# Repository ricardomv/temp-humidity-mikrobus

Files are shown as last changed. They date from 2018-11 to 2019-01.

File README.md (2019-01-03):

# temp-humidity-mikrobus
MikroBus sensor board for temperature and humidity.

Tested with:
 - [Microchip Explorer 16/32 Dev Kit](https://www.microchip.com/DevelopmentTools/ProductDetails/DM240001-2) using PIC24FJ1024GB610
 - Raspberry Pi 3 with [Pi 3 click shield](https://www.mikroe.com/pi-3-click-shield)
 
## Build

Raspberry Pi:

Install bcm2835 linux library

`cd raspberry; make`

Microchip Explorer 16/32:

 - Open MPLabX IDE
 - Open project `temp-humid.X`
 - Press Build

## Components

 - [MCP3201 - 12-Bit A/D Converter with SPI™](https://www.microchip.com/wwwproducts/en/MCP3201)
 - [HIH-5030 - Humidity Sensor](https://sensing.honeywell.com/sensors/humidity-sensors/HIH-5030-5031-series)
 - [AD592 - Current Output – Precision IC Temperature Transducer](https://www.analog.com/en/products/ad592.html)
 - [MCP1501 - Voltage reference](https://www.microchip.com/wwwproducts/en/MCP1501)
 - [1040310 - microSD Memory Card Connector](https://www.molex.com/molex/products/datasheet.jsp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)

## PCB (compatible with mikroBUS™)



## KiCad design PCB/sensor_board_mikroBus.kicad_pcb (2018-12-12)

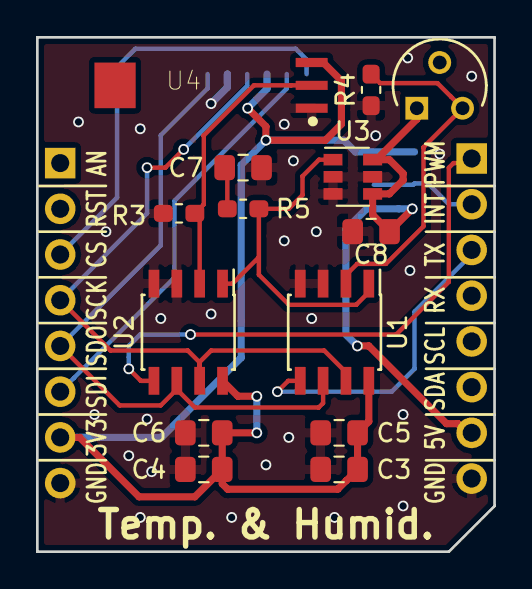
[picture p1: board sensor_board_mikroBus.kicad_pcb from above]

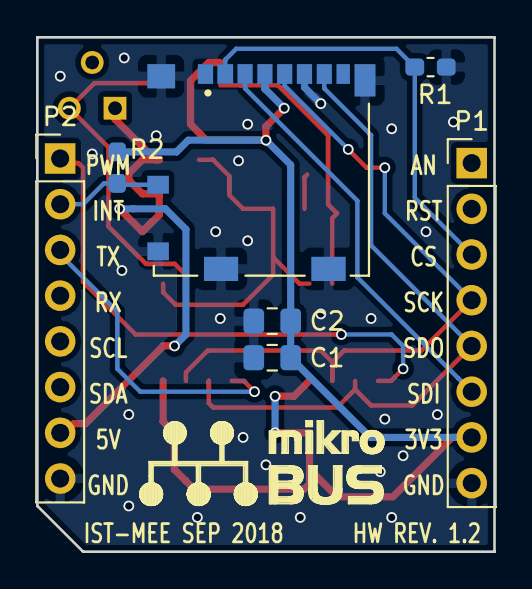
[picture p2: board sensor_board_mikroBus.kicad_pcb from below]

Board: 2 copper layers, 25.4 x 28.6 mm, 21 parts (7 on the bottom side), 14 nets.

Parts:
C1, C3, C4: 10uF; C_0805_2012Metric_Pad1.15x1.40mm_HandSolder
C2: 100nF; C_0805_2012Metric_Pad1.15x1.40mm_HandSolder
C5, C6: 1uF; C_0805_2012Metric_Pad1.15x1.40mm_HandSolder
C7, C8: 2.2uF; C_0805_2012Metric_Pad1.15x1.40mm_HandSolder
J1: Molex_0475710001; MOLEX_104031-0811
P1, P2: HEADER_M_2.54MM_1R8P_ST_AU_PTH; PinHeader_1x08_P2.54mm_Vertical
R1, R2: 100k; R_0603_1608Metric_Pad1.05x0.95mm_HandSolder
R3: 65k; R_0603_1608Metric_Pad1.05x0.95mm_HandSolder
R4: 2k; R_0603_1608Metric_Pad1.05x0.95mm_HandSolder
R5: 50R; R_0603_1608Metric_Pad1.05x0.95mm_HandSolder
U1, U2: MCP3201; SOIC-8_3.9x4.9mm_P1.27mm
U3: MCP1501-SOT-23; SOT-23-6
U4: HIH-5030-001; HONEYWELL_HIH-5030-001
U5: AD592BN; TO127P520X660-3P

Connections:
+3.3V: C1.1, C2.1, C3.1, C4.1, C5.1, C6.1, J1.4, P1.7, R2.2, U1.8, U2.8, U4.3
+5V: C8.1, P2.7, U3.4, U3.6, U5.1
CS: J1.2, P1.3, R1.1
GND: C1.2, C2.2, C3.2, C4.2, C5.2, C6.2, C7.2, C8.2, J1.6, J1.10, J1.G1, J1.G2, J1.G3, J1.G4, P1.8, P2.8, R1.2, R3.1, R4.1, U1.3, U1.4, U2.3, U2.4, U3.2, U3.3, U3.5, U4.1
INT: J1.9, P2.2, R2.1
MISO: J1.7, P1.5, U1.6, U2.6
MOSI: J1.3, P1.6
unnamed: C7.1, R5.1
PWM: P2.1, U2.5
SCK: J1.5, P1.4, U1.7, U2.7
TX: P2.3, U1.5
V_in_humid: R3.2, U2.2, U4.2
V_in_temp: R4.2, U1.2, U5.3
Vref: R5.2, U1.1, U2.1, U3.1

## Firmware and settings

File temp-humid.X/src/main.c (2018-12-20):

/*
 * File:   main.c
 * Author: ricardo
 *
 * Created on November 15, 2018, 11:05 PM
 */

#include "xc.h"
#include <stdio.h>
#include <stdlib.h>
#include <string.h>
#include <time.h>

#include "periph/spi.h"
#include "periph/mcu.h"
#include "periph/gpio.h"
#include "periph/core_timer.h"
#include "periph/periph_conf.h"
#include "periph/timer1.h"
#include "periph/timer.h"
#include "periph/watchdog.h"
#include "periph/uart.h"
#include "periph/rtcc.h"

#include "drivers/sdcard.h"
#include "drivers/sdcard_cache.h"
#include "drivers/mbr.h"
#include "drivers/lcd.h"
#include "drivers/mcp3201.h"
#include "drivers/sensors.h"

#include "fat16/fat16.h"

#include "utils.h"
#include "explorer1632.h"

#define VREF_ADC              3.3  // V

#ifndef FIRMWARE_VERSION
#define FIRMWARE_VERSION "dev"
#endif

static const char *welcome_msg = "Proj SEP firmware " FIRMWARE_VERSION
                                 " - " __DATE__ " " __TIME__
                                 "\n";

/* Pins for SPI communication */
#define SCK_PIN               GPIO_PIN(PORT_G, 6)
#define MISO_PIN              GPIO_PIN(PORT_G, 7)
#define MOSI_PIN              GPIO_PIN(PORT_G, 8)

/* Pins for SD card */
#define SD_CS_PIN             GPIO_PIN(PORT_G, 9)

/* Pins for ADCs */
#define TEMP_ADC_CS_PIN       GPIO_PIN(PORT_C, 4)  // pin 52 pim / 95 device / RX mikrobus
#define HUMID_ADC_CS_PIN      GPIO_PIN(PORT_D, 0)  // pin 72 / PWM mikrobus

/* Pins for UART interface */
#define UART_TX_PIN          (GPIO_PIN(PORT_F, 5))
#define UART_RX_PIN          (GPIO_PIN(PORT_F, 4))

static struct storage_dev_t dev = {
    sdcard_cache_read,
    sdcard_cache_read_byte,
    sdcard_cache_write,
    sdcard_cache_seek
};

struct sdcard_spi_dev_t sdcard_dev;
struct mcp3201_spi_dev_t temp_adc_dev;
struct mcp3201_spi_dev_t humid_adc_dev;

unsigned int sampling = 1;
int sample_fd = 255;
float temp_degree_C = 0;
unsigned int true_RH = 0;

struct sdcard_cache_stats_t stats;

struct tm current_time;

uint32_t millis;
uint32_t aquisition_secs = 86400;

void timer2_callback(void)
{
    char date_str[10];
    char write_size[7] = {0};
    gpio_toggle(LED_D3_PIN);
    LCD_ClearScreen();
    LCD_PutString("T:", 3);
    LCD_PutInt(temp_degree_C);
    LCD_PutChar('.');
    LCD_PutInt(abs((int)(temp_degree_C*10)%10));
    LCD_PutString("\xDF""C H:", 5);
    LCD_PutInt(true_RH);
    LCD_PutString("%\n\r",3);
    strftime(date_str, sizeof(date_str), "%T", &current_time);
    LCD_PutString(date_str, sizeof(date_str));
    stats = sdcard_cache_get_stats();
    LCD_PutString(" ",1);
    readable_fs(1024*stats.write_success/2, write_size);
    LCD_PutString(write_size, sizeof(write_size));
}

void data_aquisition(void)
{
    int ret;
    char buffer[30];
    char date_str[20];
    unsigned int len = 0;
    float sensor_RH;

    RTCC_TimeGet(&current_time);

    temp_degree_C = ad592_get_temp_degree_c(
            mcp3201_get_voltage(&temp_adc_dev));
    sensor_RH = hih5030_get_sensor_rh(
            mcp3201_get_voltage(&humid_adc_dev), humid_adc_dev.v_ref);

    true_RH = hih5030_get_true_rh(sensor_RH, temp_degree_C);

    strftime(date_str, sizeof(date_str), "%T", &current_time);

    sprintf(buffer, "%s.%lu %.1f %d\n", date_str,
                                        core_timer_get_ticks() - millis,
                                        (double)temp_degree_C,
                                        true_RH);

    if (sample_fd != 255) {
        len = strlen(buffer);
        ret = fat16_write(sample_fd, buffer, len);
        if (ret < 0 || (unsigned int)ret != len) {
            fat16_close(sample_fd);
            DBG_error("failed to write to file\n");
        }
    }
    else
        printf("%s", buffer);
}

void rtcc_alarm_callback(void)
{
    gpio_toggle(LED_D4_PIN);
    if(--aquisition_secs == 0) sampling = 0;
    millis = core_timer_get_ticks();
}

void configure_periph()
{
    mcu_set_system_clock(30000000LU);
    watchdog_disable();

    // DCOFSEL 30 MHz;
    DCOCONbits.DCOFSEL = 0xF;

    /* Configure timer 1 to enable mcu_delay, 1 tick = 1ms */
    timer1_power_up();
    timer1_configure(TIMER1_PRESCALER_1, 14565, 1);
    timer1_start();
    
    /* UART1 */
    gpio_init_out(UART_TX_PIN, 1);
    gpio_init_in(UART_RX_PIN);
    RPOR8bits.RP17R = 3;    // RP17 tx
    RPINR18bits.U1RXR = 10; // RP10 rx
    
    /* Configure timer 2 to blink LED */
    timer_power_up(TIMER_2);
    timer_configure(TIMER_2, TIMER2_PRESCALER_256, 15000, 1);

    /* Configure rtcc */
    RTCC_Initialize();
    
    LCD_Initialize();
    DBG("LCD Initialized\n");
    
    /* SPI2 */
    gpio_init_out(MOSI_PIN, 0);
    gpio_init_in(MISO_PIN);
    gpio_init_out(SCK_PIN, 0);
    RPOR9bits.RP19R = 0x000a;       /* SPI1 - MOSI */
    RPINR22bits.SDI2R = 0x001a;     /* SPI1 - MISO */
    RPOR10bits.RP21R = 0x000b;        /* SPI1 - SCK */
    gpio_init_out(SD_CS_PIN, 1);
    gpio_init_out(TEMP_ADC_CS_PIN, 1);
    gpio_init_out(HUMID_ADC_CS_PIN, 1);
    
    gpio_init_out(LED_D3_PIN, 0);
    gpio_init_out(LED_D4_PIN, 0);
    gpio_init_in(BUTTON_S3_PIN);

    /* Configure spi */
    spi_power_up(SPI_2);
    spi_configure(SPI_2, 400000, SPI_MODE_0);
    spi_enable(SPI_2);
    
    /* Configure uart */
    uart_power_up(UART_1);
    if(uart_configure(UART_1, UART_BD_115200))
        DBG_error("Failed to configure UART\n");
    uart_enable(UART_1);
}

#define DATE_CMD "SET_DATE"
#define DATE_CMD_LEN 8

void sync_time(void)
{
    struct tm *time_info;
    char cmd[9] = {0};
    int count;
    time_t rawtime;

    do {
        count = uart_read_noblock(UART_1, cmd, DATE_CMD_LEN);
    }
    while(count == 0 && gpio_read(BUTTON_S3_PIN));

    if (!count || cmd[0] == '\r')
        return;

    if (DATE_CMD_LEN - count > 0)
        uart_read(UART_1, cmd+count, DATE_CMD_LEN - count);

    if (strncmp(cmd, DATE_CMD, DATE_CMD_LEN))
        DBG_error( "Setting rtcc time\n" );

    uart_read(UART_1, &rawtime, sizeof(rawtime));
    time_info = localtime(&rawtime);
    RTCC_TimeSet(time_info);

    printf ("Current local time and date: %s", asctime(time_info));
    strftime(cmd, sizeof(cmd), " %H:%M", time_info);
    LCD_PutString(cmd, 6);
}

int main(void) {
    uint32_t partition_offset;
    struct tm current_time = {0};
    char filename[14] = "/SAMPLES.TXT\0";
    
    configure_periph();

    printf("\033[2J"); // Clear console
    printf(welcome_msg);
    
    print_reset_cause();
    
    LCD_ClearScreen();
    LCD_PutString("Press S3 to \n\rstart/stop", 24);

    sync_time();

    temp_adc_dev.spi_num = SPI_2;
    temp_adc_dev.cs_pin = TEMP_ADC_CS_PIN;
    temp_adc_dev.v_ref = VREF_ADC;

    humid_adc_dev.spi_num = SPI_2;
    humid_adc_dev.cs_pin = HUMID_ADC_CS_PIN;
    humid_adc_dev.v_ref = VREF_ADC;

    sdcard_dev.spi_num = SPI_2;
    sdcard_dev.cs_pin = SD_CS_PIN;
    
    while(gpio_read(BUTTON_S3_PIN));
    while(!gpio_read(BUTTON_S3_PIN)); // wait for button release
    
    RTCC_TimeGet(&current_time);
    if (current_time.tm_year != 100)
        strftime(filename, sizeof(filename), "/%Y%m%d.TXT", &current_time);

    if (!sdcard_init(&sdcard_dev))
        DBG("Failed SD card initialization\n");
    sdcard_cache_init(sdcard_dev);

    partition_offset = find_fat16_partition(&sdcard_dev);
    if (partition_offset > 0) {
        /* Convert partition_offset from block to byte */
        partition_offset *= SDCARD_BLOCK_LENGTH;
        fat16_init(dev, partition_offset);

        sample_fd = fat16_open(filename, 'w');
        if (sample_fd < 0)
            DBG_error("Failed to open file \"%s\" for write\n", filename);
    }
    else
        DBG( "Reading SD card\n" ) ;
    
    /* Start statistics timer*/
    timer_start(TIMER_2);
    
    RTCC_AlarmSet(&current_time, EVERY_SECOND, 0, true);
    IEC3bits.RTCIE = 1;     // Enable alarm interrupt

    /* Start data acquisition*/
    while(sampling && gpio_read(BUTTON_S3_PIN)) data_aquisition();
    
    fat16_close(sample_fd);
    sdcard_cache_flush();
    
    stats = sdcard_cache_get_stats();
    printf("\nStatistics of the SD card cache:\n");
    printf("Evictions: %lu\n", stats.evictions);
    printf("Write success: %lu\n", stats.write_success);
    printf("Read success: %lu\n", stats.read_success);
    printf("Write error: %lu\n", stats.write_error);
    printf("Read error: %lu\n", stats.read_error);

    printf("Entering mcu sleep mode.\n");
    LCD_PutString("\n\rDONE            ", 18);

    IEC3bits.RTCIE = 0;     // Enable alarm interrupt

    mcu_sleep();

    return 0;
}

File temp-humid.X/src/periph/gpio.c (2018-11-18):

/*
 * Copyright (C) 2017  Francois Berder <fberder@outlook.fr>
 *
 * This file is part of pic24-framework.
 *
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
 * You should have received a copy of the GNU General Public License
 * along with pic24-framework.  If not, see <http://www.gnu.org/licenses/>.
 */

#include <xc.h>
#include "gpio.h"
#include "periph_conf.h"

    #define GPIO_INDEX(pin)     ((pin) & 0x0F)
    #define GPIO_PORT(pin)      (((pin) >> 4) & 0x0F)
    #define GPIO_MASK(pin)      (1U << GPIO_INDEX(pin))

void gpio_init_out(uint8_t pin, uint8_t val)
{
    unsigned int port = GPIO_PORT(pin);
    unsigned int mask = GPIO_MASK(pin);

    switch (port) {
    case PORT_A:
        ANSA &= ~mask;
        ODCA &= ~mask;
        if (val)
            LATA |= mask;
        else
            LATA &= ~mask;
        TRISA &= ~mask;
        break;
    case PORT_B:
        ANSB &= ~mask;
        ODCB &= ~mask;
        if (val)
            LATB |= mask;
        else
            LATB &= ~mask;
        TRISB &= ~mask;
        break;
    case PORT_C:
        ANSC &= ~mask;
        ODCC &= ~mask;
        if (val)
            LATC |= mask;
        else
            LATC &= ~mask;
        TRISC &= ~mask;
        break;
    case PORT_D:
        ANSD &= ~mask;
        ODCD &= ~mask;
        if (val)
            LATD |= mask;
        else
            LATD &= ~mask;
        TRISD &= ~mask;
        break;
    case PORT_E:
        ANSE &= ~mask;
        ODCE &= ~mask;
        if (val)
            LATE |= mask;
        else
            LATE &= ~mask;
        TRISE &= ~mask;
        break;
    case PORT_F:
        ANSF &= ~mask;
        ODCF &= ~mask;
        if (val)
            LATF |= mask;
        else
            LATF &= ~mask;
        TRISF &= ~mask;
        break;
    case PORT_G:
        ANSG &= ~mask;
        ODCG &= ~mask;
        if (val)
            LATG |= mask;
        else
            LATG &= ~mask;
        TRISG &= ~mask;
        break;
    }
}

void gpio_init_in(uint8_t pin)
{
    unsigned int port = GPIO_PORT(pin);
    unsigned int mask = GPIO_MASK(pin);

    switch (port) {
    case PORT_A:
        ANSA &= ~mask;
        TRISA |= mask;
        break;
    case PORT_B:
        ANSB &= ~mask;
        TRISB |= mask;
        break;
    case PORT_C:
        ANSC &= ~mask;
        TRISC |= mask;
        break;
    case PORT_D:
        ANSD &= ~mask;
        TRISD |= mask;
        break;
    case PORT_E:
        ANSE &= ~mask;
        TRISE |= mask;
        break;
    case PORT_F:
        ANSF &= ~mask;
        TRISF |= mask;
        break;
    case PORT_G:
        ANSG &= ~mask;
        TRISG |= mask;
        break;
    }
}

void gpio_write(uint8_t pin, uint8_t val)
{
    unsigned int port = GPIO_PORT(pin);
    unsigned int mask = GPIO_MASK(pin);

    switch (port) {
    case PORT_A:
        if (val)
            LATA |= mask;
        else
            LATA &= ~mask;
        break;
    case PORT_B:
        if (val)
            LATB |= mask;
        else
            LATB &= ~mask;
        break;
    case PORT_C:
        if (val)
            LATC |= mask;
        else
            LATC &= ~mask;
        break;
    case PORT_D:
        if (val)
            LATD |= mask;
        else
            LATD &= ~mask;
        break;
    case PORT_E:
        if (val)
            LATE |= mask;
        else
            LATE &= ~mask;
        break;
    case PORT_F:
        if (val)
            LATF |= mask;
        else
            LATF &= ~mask;
        break;
    case PORT_G:
        if (val)
            LATG |= mask;
        else
            LATG &= ~mask;
        break;
    }
}

int gpio_read(uint8_t pin)
{
    unsigned int port = GPIO_PORT(pin);
    unsigned int mask = GPIO_MASK(pin);

    switch (port) {
    case PORT_A:
        return PORTA & mask;
    case PORT_B:
        return PORTB & mask;
    case PORT_C:
        return PORTC & mask;
    case PORT_D:
        return PORTD & mask;
    case PORT_E:
        return PORTE & mask;
    case PORT_F:
        return PORTF & mask;
    case PORT_G:
        return PORTG & mask;
    default:
        return -1;
    }
}

void gpio_toggle(uint8_t pin)
{
    unsigned int port = GPIO_PORT(pin);
    unsigned int mask = GPIO_MASK(pin);

    switch (port) {
    case PORT_A:
        LATA ^= mask;
        break;
    case PORT_B:
        LATB ^= mask;
        break;
    case PORT_C:
        LATC ^= mask;
        break;
    case PORT_D:
        LATD ^= mask;
        break;
    case PORT_E:
        LATE ^= mask;
        break;
    case PORT_F:
        LATF ^= mask;
        break;
    case PORT_G:
        LATG ^= mask;
        break;
    }
}

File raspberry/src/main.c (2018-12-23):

// Copyright (c) 2018 Ricardo Marcelino Vieira ricardo.vieira@tecnico.ulisboa.pt
//
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
#include <stdio.h>
#include <bcm2835.h>
#include "sensors.h"
#include "mcp3201.h"

#define VREF_ADC              3.3  // V

#define TEMP_ADC_CS_PIN       RPI_V2_GPIO_P1_10
#define HUMID_ADC_CS_PIN      RPI_V2_GPIO_P1_12

int main(void) {
    struct mcp3201_spi_dev_t temp_adc_dev;
    struct mcp3201_spi_dev_t humid_adc_dev;
    float temp_degree_C = 0;
    float sensor_RH;
    unsigned int true_RH = 0;

    // If you call this, it will not actually access the GPIO
    // Use for testing
    // bcm2835_set_debug(1);

    if (!bcm2835_init())
    {
      printf("bcm2835_init failed. Are you running as root??\n");
      return 1;
    }
    if (!bcm2835_spi_begin())
    {
      printf("bcm2835_spi_begin failed. Are you running as root??\n");
      return 1;
    }

    temp_adc_dev.spi_num = 0;
    temp_adc_dev.cs_pin = TEMP_ADC_CS_PIN;
    temp_adc_dev.v_ref = VREF_ADC;

    mcp3201_init(&temp_adc_dev);

    humid_adc_dev.spi_num = 0;
    humid_adc_dev.cs_pin = HUMID_ADC_CS_PIN;
    humid_adc_dev.v_ref = VREF_ADC;

    mcp3201_init(&humid_adc_dev);

    temp_degree_C = ad592_get_temp_degree_c(
            mcp3201_get_voltage(&temp_adc_dev));
    sensor_RH = hih5030_get_sensor_rh(
            mcp3201_get_voltage(&humid_adc_dev), humid_adc_dev.v_ref);

    true_RH = hih5030_get_true_rh(sensor_RH, temp_degree_C);

    printf("%.1f %d\n",temp_degree_C, true_RH);

    bcm2835_spi_end();
    return 0;
}

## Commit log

2018-11-18 Working uSD card and ADC
2018-11-18 Use timer to blink led.
2018-11-18 Use timer3 for data acquisition
2018-11-19 Add uart peripheral
2018-11-20 Add function LCD_PutLongInt to LCD driver
2018-11-20 Add one more ADC to aquire Temperature and humidity simultaneosly
2018-11-20 Lower sample count for now
2018-11-28 Make propper sensor values calculation
2018-11-29 Display sdcard statistics in LCD and UART
2018-12-01 Add PCB schematic and layout
    [sensor_board_mikroBus.kicad_pcb, sensor_board_mikroBus.sch]
2018-12-02 Add alarm code to RTC peripheral Currently only blinks led D4 every second 24 times This will be used to change files dutring aquisition
2018-12-02 Change clock frequency in ADC SPI comunication
2018-12-02 Cleanup code that changes SPI baudrate
2018-12-03 Change CS pin for the temperature ADC
2018-12-03 Change temperature variable type to float
2018-12-05 PCB: Change sdcard pin connected to ground.
    [sensor_board_mikroBus.kicad_pcb, sensor_board_mikroBus.sch]
2018-12-05 PCB: Update revision
    [sensor_board_mikroBus.kicad_pcb]
2018-12-06 Add development board components
2018-12-09 Fix calculations for ADC voltage
    [mcp3201.c]
2018-12-09 Use also button S3 to stop data aquisition
2018-12-09 Fix uart_read_noblock to return number of bytes read from uart
    [uart.c]
2018-12-09 Sync rtcc time from UART
2018-12-09 Count seconds until end of data aquisiton with rtcc interrupt
2018-12-09 Print error messages only one time
2018-12-12 PCB: Fix noise generated by sensor in Vref
    [sensor_board_mikroBus.kicad_pcb, sensor_board_mikroBus.sch]
2018-12-20 PCB: Add schematic subtitle
    [sensor_board_mikroBus.sch]
2018-12-20 Change interface using the buttons and LCD
2018-12-23 Add Raspberry Pi 2B/3B code to read sensor values

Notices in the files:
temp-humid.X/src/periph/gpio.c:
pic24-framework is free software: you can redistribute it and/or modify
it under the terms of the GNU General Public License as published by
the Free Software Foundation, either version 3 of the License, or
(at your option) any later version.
